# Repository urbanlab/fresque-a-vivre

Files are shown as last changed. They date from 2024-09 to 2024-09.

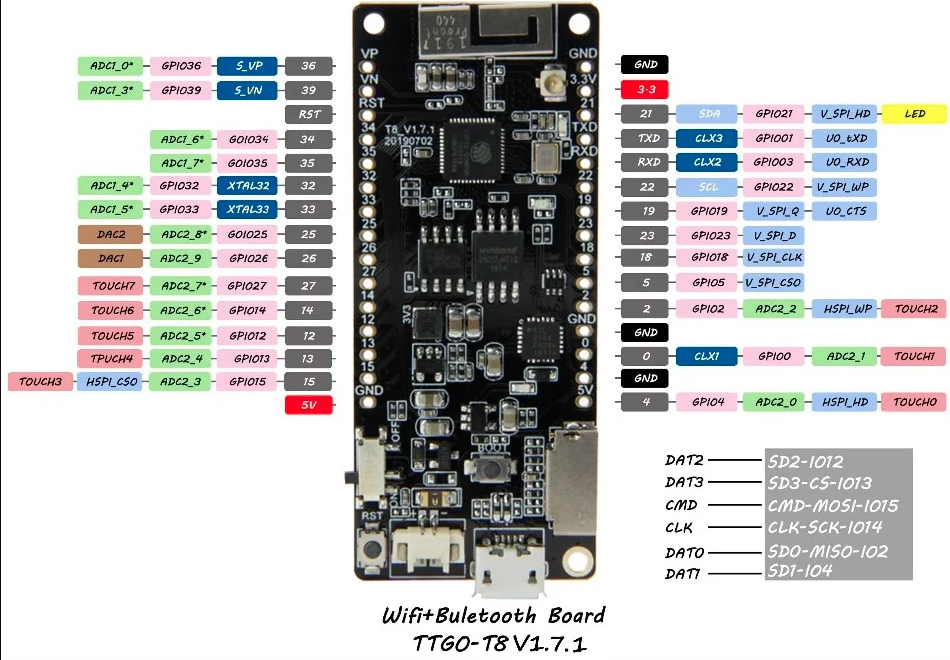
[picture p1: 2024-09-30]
Docs/pinout_TTGO-T8-V1.png

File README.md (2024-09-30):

This version of the "Fresque_sonore" was made by Jérémie FORGE (Hémisphère project), to deploy the prototype "Fresque-a-vivre" in the "Maison du projet de la Saulaie", a place to explore the district of "La Saulaie" (Oullins 69 - France).
The source of this branch is here : https://github.com/Hemisphere-Project/Ouidire

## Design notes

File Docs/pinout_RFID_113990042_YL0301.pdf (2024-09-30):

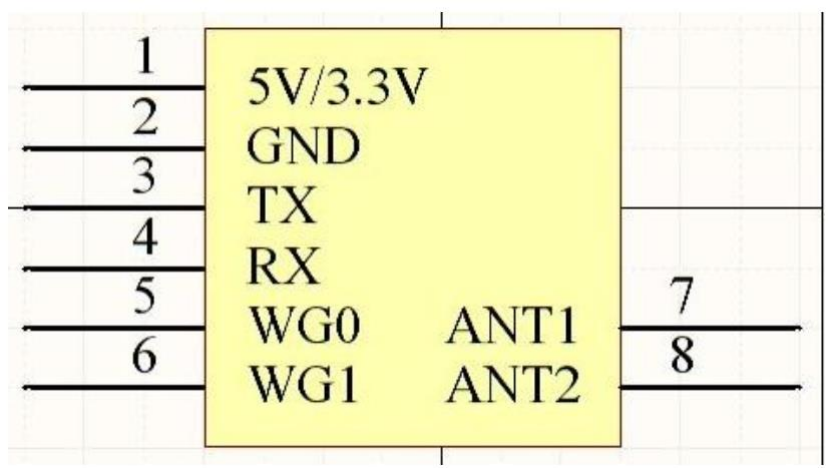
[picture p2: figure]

Pin Number | Pin Name | Instruction
1 | 5V/3.3V | Power supply 5V/3.3V
2 | GND | Ground
3 | TX | Serial data transmitting
4 | RX | Serial data receiving (Reserved)
5 | WG0 | Wiegand data 0 out (Reserved)
6 | WG1 | Wiegand data 1 out (Reserved)
7 | ANT1 | Antenna 1
8 | ANT2 | Antenna 2

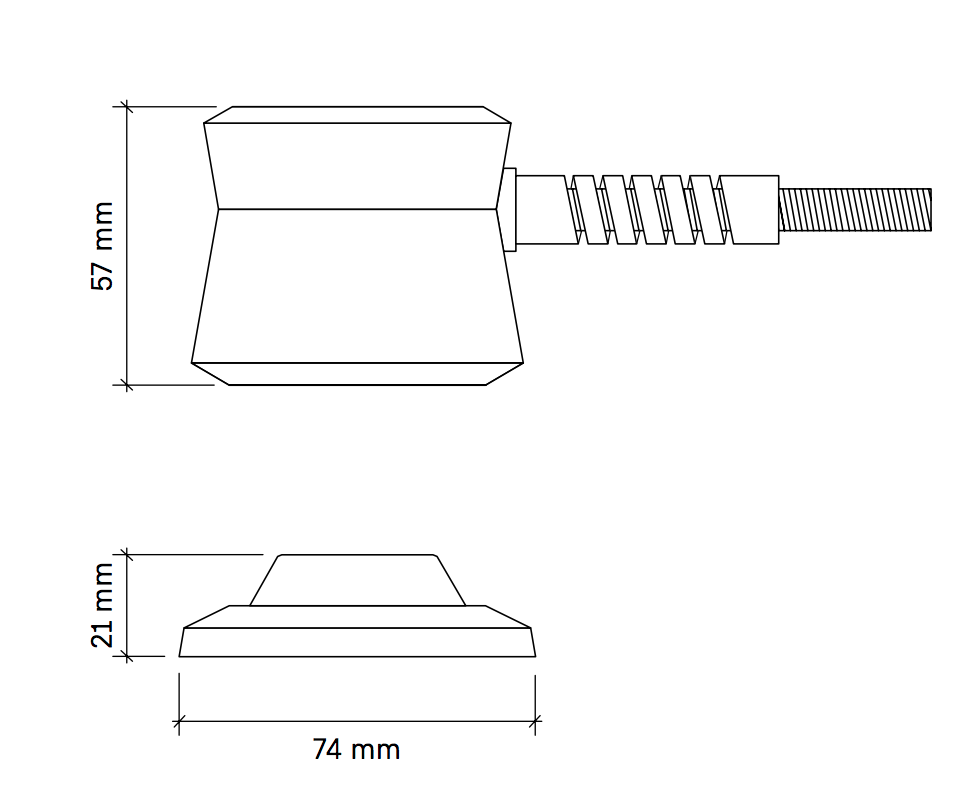
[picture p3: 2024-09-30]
Casing/Doc/Molitor USO.png

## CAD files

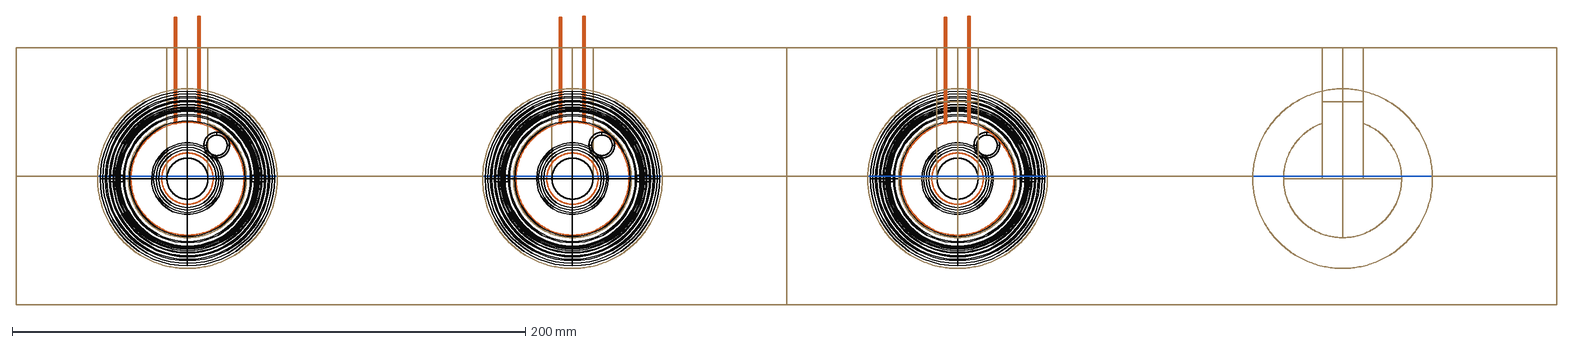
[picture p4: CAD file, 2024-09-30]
Casing/Dock/Dock.dxf
600.0 x 112.3 mm

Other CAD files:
Casing/Boitier_v1/Boitier.3dm
Casing/Boitier_v1/Bot.3dm
Casing/Boitier_v1/Top.3dm
Casing/Boitier_v2/BOT_v2.3dm
Casing/Boitier_v2/Boitier_v2.3dm
Casing/Boitier_v2/TOP_v2.3dm
Casing/Boitier_v3/Boitier_v3.3dm
Casing/Boitier_v3/Bot_v3.3dm
Casing/Boitier_v3/Top_v3.3dm

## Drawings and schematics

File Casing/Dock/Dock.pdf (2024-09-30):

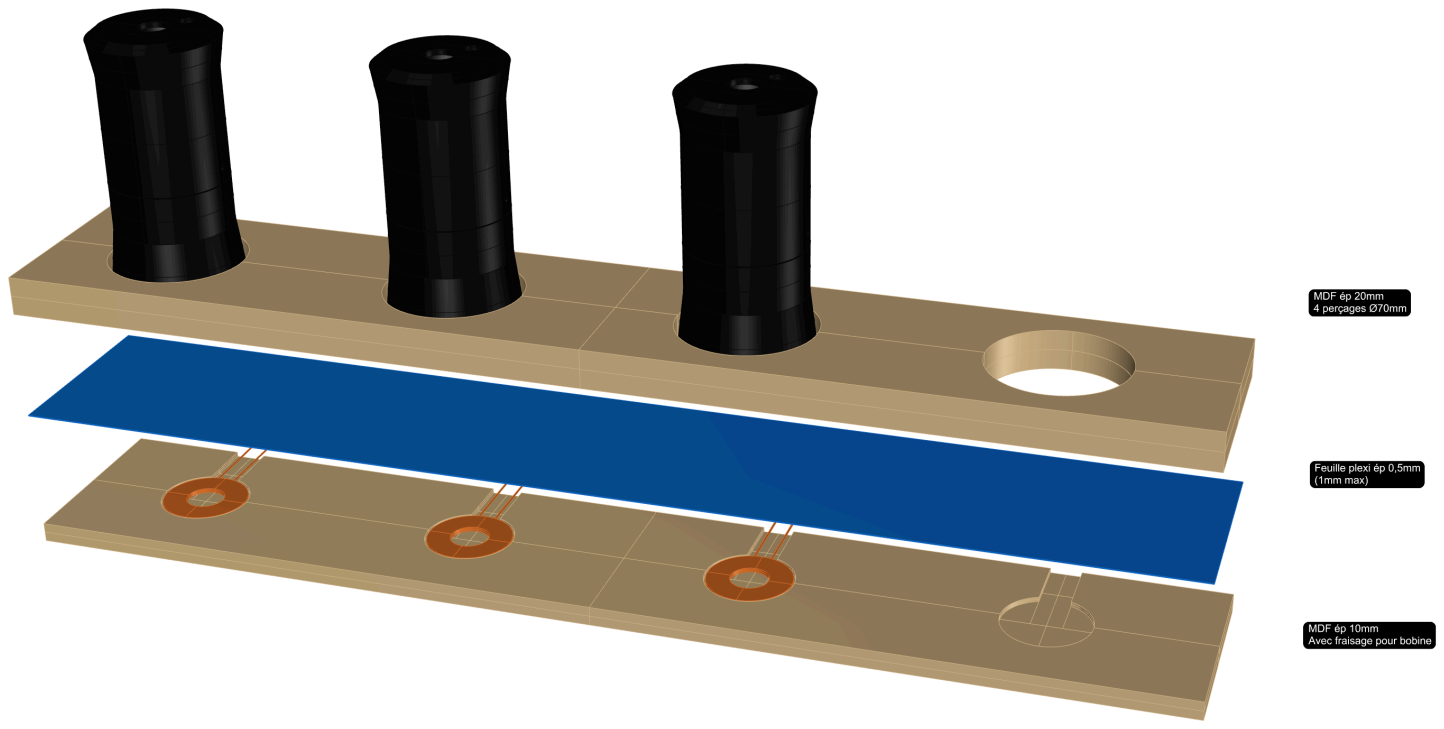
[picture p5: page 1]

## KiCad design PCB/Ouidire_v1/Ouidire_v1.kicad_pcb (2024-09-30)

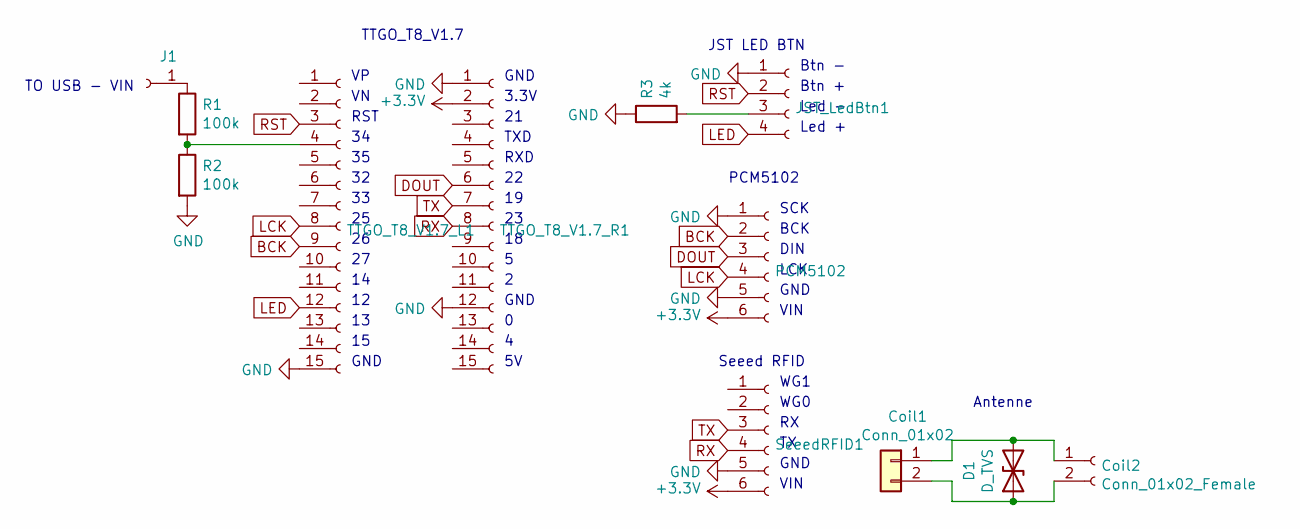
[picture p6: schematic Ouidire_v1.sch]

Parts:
Coil1: Conn_01x02; PinSocket_1x02_P2.54mm_Vertical
Coil2: Conn_01x02_Female; PinSocket_1x02_P2.54mm_Vertical
D1: D_TVS; D_DO-35_SOD27_P7.62mm_Horizontal
J1: Conn_01x01_Female; PinSocket_1x01_P2.54mm_Vertical
JST_LedBtn1: Conn_01x04_Female; PinSocket_1x04_P2.54mm_Vertical
PCM5102: Conn_01x06_Female; PinSocket_1x06_P2.54mm_Vertical
R1, R2: 100k; R_1206_3216Metric_Pad1.42x1.75mm_HandSolder
R3: 4k; R_1206_3216Metric_Pad1.42x1.75mm_HandSolder
SeeedRFID1: Conn_01x06_Female; PinSocket_1x06_P2.54mm_Vertical
TTGO_T8_V1.7_L1, TTGO_T8_V1.7_R1: Conn_01x15_Female; PinSocket_1x15_P2.54mm_Vertical

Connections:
+3V3: PCM5102.6, SeeedRFID1.6, TTGO_T8_V1.7_R1.2
BCK: PCM5102.2, TTGO_T8_V1.7_L1.9
DOUT: PCM5102.3, TTGO_T8_V1.7_R1.6
GND: JST_LedBtn1.1, PCM5102.1, PCM5102.5, R2.2, R3.1, SeeedRFID1.5, TTGO_T8_V1.7_L1.15, TTGO_T8_V1.7_R1.1, TTGO_T8_V1.7_R1.12
LCK: PCM5102.4, TTGO_T8_V1.7_L1.8
LED: JST_LedBtn1.4, TTGO_T8_V1.7_L1.12
unnamed: Coil1.1, Coil2.1, D1.2 (A2)
unnamed: Coil1.2, Coil2.2, D1.1 (A1)
unnamed 8: J1.1, R1.1; also elsewhere on the board
unnamed: JST_LedBtn1.3, R3.2
unnamed: R1.2, R2.1, TTGO_T8_V1.7_L1.4
RST: JST_LedBtn1.2, TTGO_T8_V1.7_L1.3
RX: SeeedRFID1.4, TTGO_T8_V1.7_R1.8
TX: SeeedRFID1.3, TTGO_T8_V1.7_R1.7

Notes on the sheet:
Antenne
TTGO_T8_V1.7
PCM5102
Seeed RFID
TO USB - VIN
JST LED BTN
Btn -
Btn +
Led -
Led +
RST
GND
3.3V
TXD
RXD
SCK
BCK
DIN
LCK
VIN
WG1
WG0

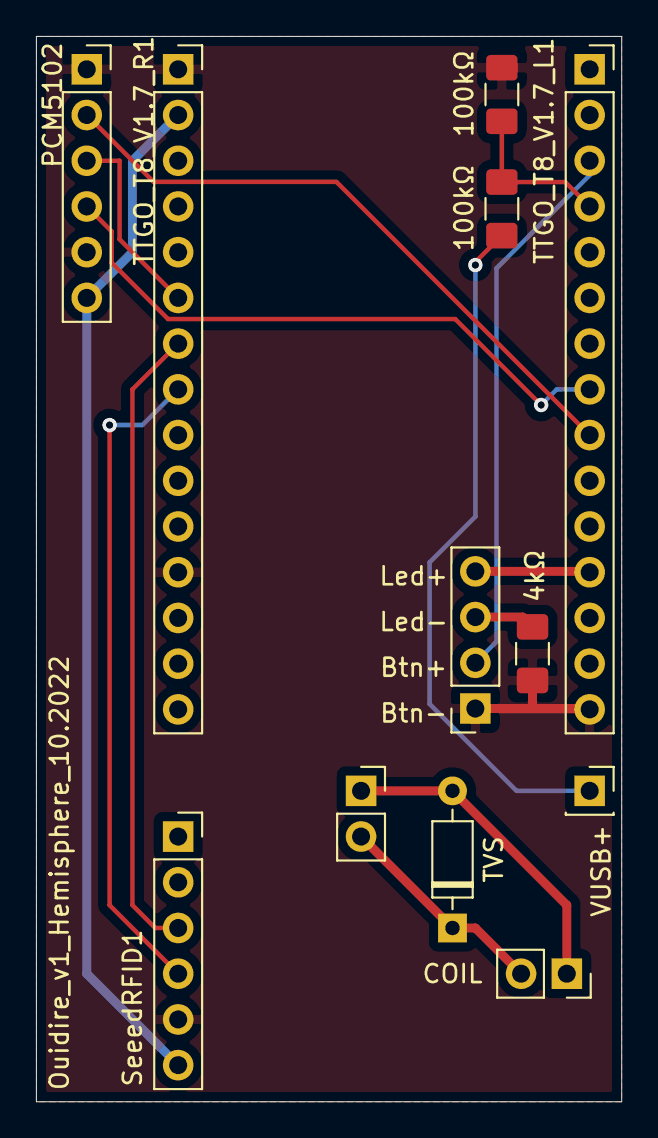
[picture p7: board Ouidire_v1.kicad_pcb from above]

Board: 2 copper layers, 32.5 x 59.2 mm, 12 parts (0 on the bottom side), 14 nets.

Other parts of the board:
VUSB+: Conn_01x01_Female; PinSocket_1x01_P2.54mm_Vertical

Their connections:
unnamed 8: VUSB+.1; also elsewhere on the board

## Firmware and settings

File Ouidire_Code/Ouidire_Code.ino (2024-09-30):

// SD
#include <Arduino.h>
#include <SD.h>
// SeeedRFID
// https://github.com/Seeed-Studio/RFID_Library
#include <SoftwareSerial.h>
#include <SeeedRFID.h>
// ESP8266Audio
// https://github.com/earlephilhower/ESP8266Audio
#include "AudioFileSourceSD.h"
#include "AudioGeneratorWAV.h"
#include "AudioOutputI2S.h"

// RFID
// TX -- 19 (RX On the RFID Side)
// RX -- 23 (TX On the RFID Side)

// SD
// SCK --- 14
// MISO -- 2
// MOSI -- 15
// CS ---- 13
// (format SD: FAT, MBR)

// DAC (PCM5102)
// bclk -- 26 (BCK)
// wclk -- 25 (LCK)
// dout -- 22 (DIN)
// SCK --- GND

// TO FLASH:
// Mac: Install USB manager CH9102 (CH34XSER_MAC)
// Click 'upload', & Turn off & on the power switch on the TTGO while arduino IDE tries to connect (after compiling)

//RFID
#define RFID_TX_PIN 19 // RX on the RFID side
#define RFID_RX_PIN 23 // TX on the RFID side
unsigned long Tdetect = 0;
unsigned long Tblink = 0;

#define DEBUG
#define VBAT_PIN 35
#define VBUS_PIN 34

// VISU
#define LED_PCB  21 // TTGO T8 INTERNAL PIN
#define LED_PIN  12 // LED BTN
int ledState = LOW;

File dir;
AudioFileSourceSD *source;
AudioOutputI2S *output;
AudioGeneratorWAV *decoder;


SeeedRFID RFID(RFID_RX_PIN, RFID_TX_PIN);
RFIDdata tag;

void setup() {
    // GLOBAL
    Serial.begin(115200);
    delay(1000);
    Serial.println("OUI DIRE");
    // SD
    SPI.begin(14, 2, 15, 13); //SCK, MISO, MOSI,SS
    SD.begin(13, SPI);
    dir = SD.open("/");
    // AUDIO
    source = new AudioFileSourceSD();
    output = new AudioOutputI2S();
    output->SetPinout(26,25,22); // BCLK, WCLK, DOUT
    decoder = new AudioGeneratorWAV();
    output->SetGain(1);//0-----1 (50% = 0.5)
    playAudio("Bonjour");
    // LEDS & INFO
    pinMode(LED_PCB, OUTPUT);
    pinMode(LED_PIN, OUTPUT);
    pinMode(VBUS_PIN, INPUT);
}

void loop() {
    updateRFID();
    updateAudio();
    updateLeds();
}

void updateRFID(){
  if (RFID.isAvailable()) {
      tag = RFID.data();
      Serial.print("RFID card number: ");
      Serial.println(RFID.cardNumber());
      Tdetect = millis();
      playAudio(String(RFID.cardNumber()));
  }
}

void updateAudio(){
  if (decoder->isRunning()) {
    if (!decoder->loop()) decoder->stop();
  } else {
    // Serial.printf("WAV done\n");
    delay(100);
  }
}

void playAudio(String cardNumber){
  Serial.println("Play /"+cardNumber+".wav");

  decoder->stop();
  source->close();
  source->open(("/"+cardNumber+".wav").c_str());
  decoder->begin(source, output);

}

void updateLeds(){

  unsigned long Tnow = millis();
  String state = "undefined";
  // detecting      LED OFF
  // charging       LED BLINK 1sec
  // normal         LED ON
  // low_battery    LED BLINK 200ms

  // BATTERY -- VBAT
  float vbat_raw = analogRead(VBAT_PIN);
  float vbat = (vbat_raw  / 4096) * 3.3 * 2 * 1.05;

  // CHARGE USB -- VBUS
  float vbus_raw = analogRead(VBUS_PIN);


  // DEFINE STATES
  // DETECT RFID
  if(Tnow-Tdetect<1000){
    state = "detecting";
  }else{
    // VBAT
    if(vbat > 3.4){
      state = "normal";
    }
    if((vbat > 3.2)&&(vbat <= 3.4)){
      state = "low_battery";
    }
    // VBUS
    if (vbus_raw > 100){
      state = "charging";
    }
  }

  // LED
  if(state=="detecting"){
    ledState = LOW;
  }
  if(state=="normal"){
    ledState = HIGH;
  }
  if(state=="low_battery"){
    if(Tnow-Tblink>100){
      Tblink = Tnow;
      if (ledState == LOW) { ledState = HIGH; }
      else { ledState = LOW; }
    }
  }
  if(state=="charging"){
    if(Tnow-Tblink>1000){
      Tblink = Tnow;
      if (ledState == LOW) { ledState = HIGH; }
      else { ledState = LOW; }
    }
  }
  digitalWrite(LED_PIN, ledState);

  // LED PCB
  if(state=="detecting"){
    digitalWrite(LED_PCB, HIGH);
  }else{
    digitalWrite(LED_PCB, LOW);
  }




}

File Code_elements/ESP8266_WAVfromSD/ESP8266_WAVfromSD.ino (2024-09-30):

#include <Arduino.h>
#include <SD.h>
#include "AudioFileSourceSD.h"
#include "AudioGeneratorWAV.h"
#include "AudioOutputI2S.h"

File dir;
AudioFileSourceSD *source;
AudioOutputI2S *output;
AudioGeneratorWAV *decoder;

// SD
// SCK --- 14
// MISO -- 2
// MOSI -- 15
// CS ---- 13

// DAC (PCM5102)
// bclk -- 26 (BCK)
// wclk -- 25 (LCK)
// dout -- 22 (DIN)
// SCK --- GND

void setup()
{
  Serial.begin(115200);
  delay(1000);
  Serial.printf("WAV start\n");

  SPI.begin(14, 2, 15, 13); //SCK, MISO, MOSI,SS
  SD.begin(13, SPI);
  dir = SD.open("/");
  // printDirectory(dir, 0);

  source = new AudioFileSourceSD();
  output = new AudioOutputI2S();
  output->SetPinout(26,25,22); // BCLK, WCLK, DOUT
  decoder = new AudioGeneratorWAV();

  output->SetGain(1.0);

  // DIRECT OPEN
  source->open("/3162207.wav");
  decoder->begin(source, output);


}

void loop()
{
  if (decoder->isRunning()) {
    if (!decoder->loop()) decoder->stop();
  } else {
    Serial.printf("WAV done\n");
    delay(1000);
  }

  // SCAN & LISTEN
  // if ((decoder) && (decoder->isRunning())) {
  //   if (!decoder->loop()) decoder->stop();
  // } else {
  //   File file = dir.openNextFile();
  //   if (file) {
  //     if (String(file.name()).endsWith(".wav")) {
  //       source->close();
  //       if (source->open(file.name())) {
  //         Serial.println(file.name());
  //         Serial.printf_P(PSTR("Playing '%s' from SD card...\n"), file.name());
  //         decoder->begin(source, output);
  //       } else {
  //         Serial.printf_P(PSTR("Error opening '%s'\n"), file.name());
  //       }
  //     }
  //   } else {
  //     Serial.println(F("Playback form SD card done\n"));
  //     delay(1000);
  //   }
  // }

}




// void printDirectory(File dir, int depth) {
//   while (true) {
//     File entry =  dir.openNextFile();
//     if (! entry)
//       break;
//
//     for (uint8_t i = 0; i < depth; i++)
//       Serial.print("|    ");
//
//     std::string name = entry.name();
//     if (entry.isDirectory()) {
//       Serial.print("+----" + String(name.substr(name.find_last_of("/\\") + 1).c_str()) + "\r\n");
//       printDirectory(entry, depth + 1);
//     } else {
//       Serial.print("+--" + String(name.substr(name.find_last_of("/\\") + 1).c_str()));
//       Serial.print("\t\t\t(");
//       Serial.print(entry.size(), DEC);
//       Serial.println(")");
//     }
//     entry.close();
//   }
// }
